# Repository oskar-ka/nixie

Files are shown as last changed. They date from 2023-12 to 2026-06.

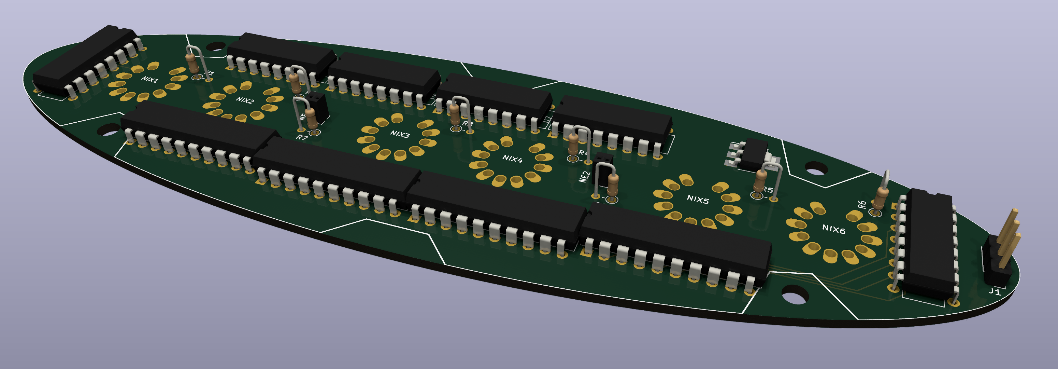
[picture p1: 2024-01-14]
pcb_v0/exports/renders/render.png

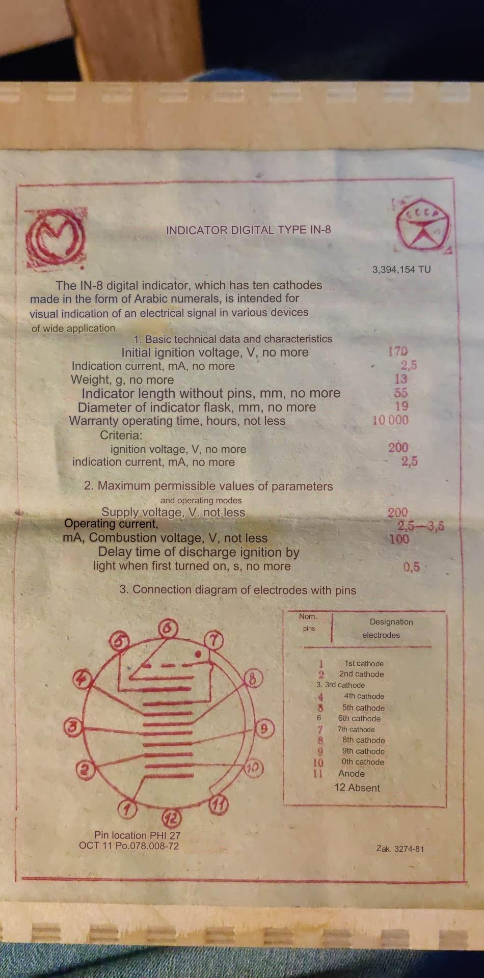
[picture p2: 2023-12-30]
datasheets/IN-8_datasheet_english.jpg

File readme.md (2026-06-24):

# Features
- 6x IN-8
- 2/4x NE-2
- GPS disciplined, temperature compensated crystal oscillator
- Lysnetspænding i EU kan lovligt variere mellem 207Vac til 253Vac, som giver halveret DC på 146-182Vdc
- Automatisk lysstyrkedæmpning
- Temperaturføler
- Komponenter skal virke ved 85C (varm dag &leq;40C+4W*10K/W=80C)

# Strømforsyning
Nixie uret skal bruge to spændinger for at fungere: 5Vdc til microcontroller og logiske kredse, samt 180Vdc til at trække nixierørene. Hvert rør kan tåle op til 3.5mA, så med 6 rør skal strømforsyningen levere 21mA + lidt til de 4 små nixie prikker, så i alt maks. 30mA v. 180Vdc. Det er nok ikke nødvendigt med PFC ved 30mA, men det kunne måske være sjovt at lave hvis der er plads til det. Evt. kan strøforsyningen blive lavet på et separat print, som kan placeres under nixie-printet, så burde der være masser af plads. Skal den kunne skifte mellem 230Vac og 120Vac, og skal den gøre det automatisk?

### Specifikationer
- Fra IN-8 datablad:
    - Ignition voltage: &leq; 170V
    - Indication current: &leq; 2.5mA
    - Turn-off voltage: ??
- NE-2 lampe:
    - &lt;1mA
- 180Vdc, 20mA
- Current limiting, [foldback](https://www.eeeguide.com/foldback-current-limiting-circuit/)

### Der findes mange forskellige måder at opnå disse to spændinger:
- 12/24Vdc indgang &rarr; DC-DC til 5V + boost converter til 180Vdc
    - [Recom R12-150B](https://www.tme.eu/dk/en/details/r12-150b/dc-dc-converters/recom/)
- 230Vac indgang &rarr; diodebro som giver 325Vdc, med den rigtige modstand før 
nixierørene kan denne spænding bruges direkte; 5V AC-DC
    - Rimelig ueffektivt og ikke så sejt, men meget nemt
    - Nixiestrøm afhængig af netspænding
- 230Vac &rarr; styret thyristorbro som giver 180Vdc direkte; 5V AC-DC
    - Thyristorbroer er som regel store, ved ikke om man kan få en i DIP
- 230Vac &rarr; styret MOSFET ensretter som giver 180Vdc direkte; 5V AC-DC
    - Mere effektiv end thyristorbro
    - Skal bruge to MOSFETS hver vej for at kunne blokere = 8 MOSFETS
    - Kan evt. også laves som halvbølgeensretter, da den ikke skal levere ret meget strøm
- ~~230Vac &rarr; halveringstransformer 230V&rarr;115Vac &rarr; ensretter (styret/ikke styret); & 5V AC-DC~~
    - ~~Ret nemt, få komponenter, ret effektivt, galvanisk adskillelse~~
    - ~~Giver 160Vdc v. 230Vac, hvilket er fint, men hvis nettet går ned til 207Vdc så har vi kun 146Vdc hvilket ikke helt er nok~~
- 230Vac &rarr; 2/3-transformer = 195/217/239Vdc (min, nom, max)
    - enten direkte til nixierør, kunne sikkert fungere
        - Her vil varmetab være i modstande og måske IC, bedre at have det centreret i en NPN med varmeplade
    - eller transistor med varmetab
        - skal smide mellem 15-59V
        - ved 20mA &rarr; 0.3W-1.2W
        - TO-92: [PHE13003A](https://mou.sr/43Gdbwc) 60K/W, nogle af dem måske op til 2W??
        - TO-252 [MJD340](https://mou.sr/4o38ar5): 8.3K/W op til 15W
        - TO-220 [BUL741](https://mou.sr/3Q8gnh7): 2K/W op til 60W
        - TO-3 [MJ15024](https://mou.sr/4uGqn01): 0.7K/W op til 250W
    - eller buck-converter?
- 230Vac &rarr; reguleret flyback converter med 2 udgange!!
    - Ret sej løsning, galvanisk adskillelse, høj virkningsgrad, ikke nemt.
    - 

Skal power supply være på et separat print?

### Varmeplader
- Fischer Eletronik SK 13
    - 17 K/W
    - Lille U-formet, mindste heatsink som kan bruges
    - Højde: 13mm
- Mindste PCB mount
    - [link](https://www.digikey.com/en/products/detail/boyd-laconia-llc/581002B02500G/1216391)
    - 17.4 K/W
    - Højde: 25.4mm
- Fischer Elektronik SK 64
    - 2.7 K/W
    - Fås i [sort](https://www.digikey.com/en/products/detail/fischer-elektronik/SK-64-37-5-SA-1-x-M3-TO-220/25827581) eller [natural](https://www.digikey.com/en/products/detail/fischer-elektronik/SK-64-37-5-ME-1-x-M3-TO-220/25828864)
    - Højde: 25mm
- [SK 65](https://fischerelektronik.de/web_fischer/en/heatsinks/A01/Standard%20extruded%20heatsinks/$catalogue/fischerData/PR/SK65_/search.xhtml) Til SOT-32 transistor, lidt lavere end SK 64
- [U-formet](https://fischerelektronik.de/web_fischer/en/heatsinks/A07/U-Extruded%20heatsinks/$catalogue/fischerData/PR/ICK35_SA_/search.xhtml), lidt større end den jeg har, 15K/W
- ~~[SK 36](https://fischerelektronik.de/web_fischer/en/heatsinks/A01/Standard%20extruded%20heatsinks/$catalogue/fischerData/PR/SK36_/search.xhtml) Sej en til TO-3~~
- [SK 31](https://fischerelektronik.de/web_fischer/en/heatsinks/A01/Standard%20extruded%20heatsinks/$catalogue/fischerData/PR/SK31_/search.xhtml) Til TO-3, kun 12mm høj
- [SK 145](https://www.fischerelektronik.de/web_fischer/en_GB/heatsinks/A01/Standard%20extruded%20heatsinks/$catalogue/fischerData/PR/SK145_/search.xhtml)
- SK 59
- SK 09
- Adam tech
    - HSK-53-01 Højde: 18.5mm
    - HSK-55-01 Højde: 18.5mm
- [680-5A](https://mou.sr/4eQcQgR)
    - 12.7mm højde
    - 46x46mm footprint

### Komponenter
- AC Sikring + sikringsholder
    - 100mA glassikring?
- Transformer:
    - [Hammond 229A230](https://www.digikey.com/en/products/detail/hammond-manufacturing/229A230/454947) Unhoused
        - Height: 21.6mm
    - [Bel Signal IF-6-230](https://mou.sr/49APmcG) Red housing
        - Height: 22.6mm
    - [Bel Signal 230-25-LPI](https://mou.sr/4x3g8o8) Black housing
        - Height: 22.7mm
    - [Bel Signal LP-230-25](https://mou.sr/4uTkMDK) Unhoused
        - Height: 21.6mm
- 5V supply:
    - [Mean Well IRM-01-5](https://mou.sr/4u9H5E1)
    - [PBO-3E/F](https://www.belfuse.com/products/power-supplies/ac-dc-converters)
    - [PSK-5E](https://www.belfuse.com/products/power-supplies/ac-dc-converters/psk-5e-series)
    - [TRACO Power TMPS 05-105](https://mou.sr/49ALLeS) 1x1"
    - [Mornsun LS05-23B05DR3](https://www.mornsun-power.com/html/pdf/LS05-23B05DR3.html) Very small
- Ensretter IC
    - sdf

# Timekeeping
Forskellige niveauer af præcision: MCUens interne RC oscillator, normal kvartskrystal, temperaturkonpenseret krystaloscillator (TCXO), ovnkontrolleret krystaloscillator (OCXO). Desuden kan en oscillator *disciplineres* mht. et præcist eksternt signal, f.eks. GPS for en stor forbedring i stabilitet.

Stratum 3??

- OCXO
    - [CTS 139VGEVS10M000](https://mou.sr/4afKvxZ)
    - Bruger en lille "ovn" til at opvarme krystallen og holde dens temperatur stabil
- TCXO
    - Typisk tilgændelige i 280ppb, hvilket er super
    - De har god temperaturstabilitet, men ikke nødvedigvis god *aging*
    - MEMS vs quartz. MEMS har bedre aging, bedre temperaturforudsigelighed, bedre dynamisk stabilitet (når temp. ændrer sig), lavere fejlrater. De er dog dyrere, har mere fasestøj, og bruger mere strøm.
    - [SiTime MEMS](https://www.sitime.com/products/ultrastable-mhz-super-tcxos/super-tcxos/sit5356)

Vi vil gerne under 1s afvigelse over et år uden GPS, dette 

# Udførsel, lagkagekasse
Bruger den første kasse der blev bygget, den laserskårede. 
6 IN-8 rør, 2 NE-2 lamper. Ingen optokoblere. 
Forsynet med 170V reguleret direkte fra ensrettet mains, derudover lille indpakket 5V AC-DC forsyning. 
Forsyning på separat print, som hænger under styreprint med 20mm standoffs, og bruger disse til forbindelse.
Ensretter, CRC filter, TO-3 transistor, (en cap mere?)
Strømindgang via IEC C7 stik uden ground, intet at bruge det til.

# Komponenter, generel
- Lamper
    - 6x IN-8
    - 2/4x NE-2
- Forsyningsprint
    - Sikring
        - 100mA
    - Transformer
    - Ensretter
    - Lyt
    - Zenerdiode(r)
        - hvis 180V så 5W
    - Effekttransistor
    - OCP transistor
    - Modstande
    - AC-DC forsyning
- Styreprint
    - ATtiny2313 x1
    - Shift register x4
    - Quad optokobler f.eks. LTV-845M x4
    - SN74141 x4
    - MPSA42 NPN transistor
    - 6x Anodemodstande til nixierør 1/2W
    - 2x Anodemodstande til NE2 lamper 1/4W

# Enclosure
### Varmeafgivelse
- Original laserskåret lagkagekasse
    - Test 1: P=4W, UT=22C, IT=67C &rarr; +45C v. 4W = 11.25 K/W
    - Test 2: P=3W, UT=22C, IT=58C &rarr; +36C v. 3W = 12    K/W
    - Test 3: P=2W, UT=22C, IT=49C &rarr; +26C v. 2W = 13.5  K/W
    - Test 4: P=1W, UT=22C, IT=38C &rarr; +16C v. 1W = 16    K/W
    
SMD keramiske kondensatorer 2.2uF 450V [her](https://mou.sr/4eBqHqi)

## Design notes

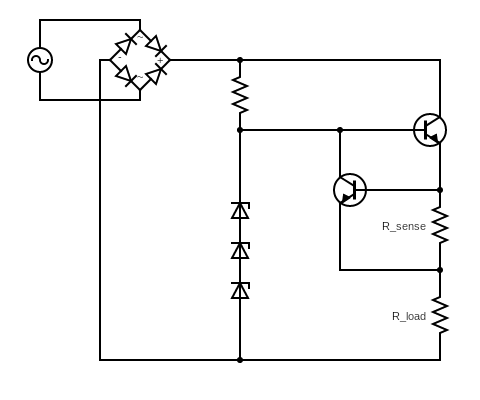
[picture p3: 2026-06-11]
HV_regulator_I_limit.png

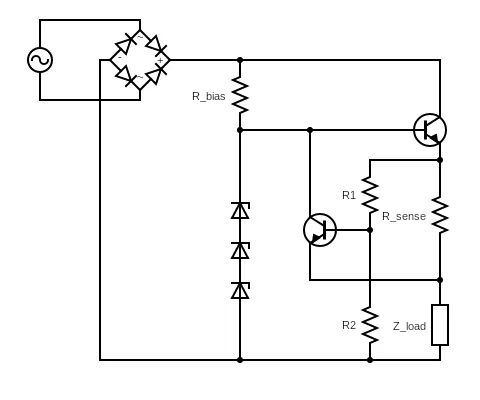
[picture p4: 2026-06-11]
HV_regulator_foldback.png

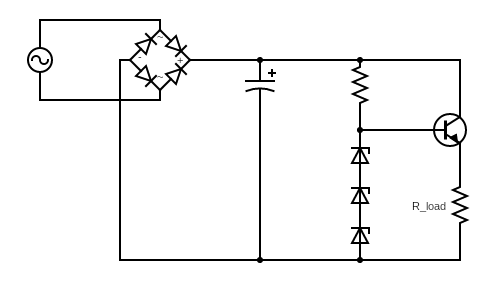
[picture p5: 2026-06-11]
HV_regulator.png

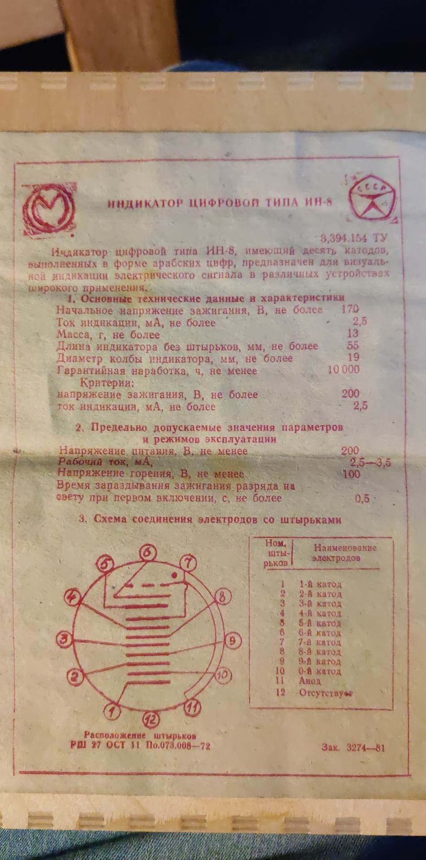
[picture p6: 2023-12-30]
datasheets/318470724_1155964738362694_6747269933038089957_n.jpg

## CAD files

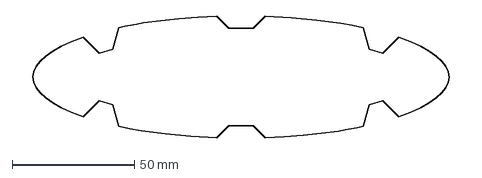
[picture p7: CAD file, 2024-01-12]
pcb_v0/pcb_component_clearance.dxf
183.7 x 49.7 mm

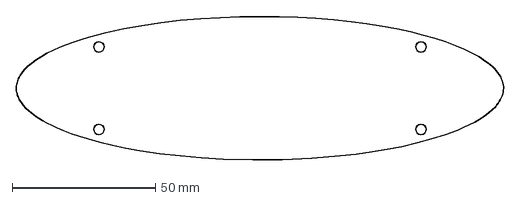
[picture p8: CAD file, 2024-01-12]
pcb_v0/pcb_edge_cuts.dxf
170.0 x 50.5 mm

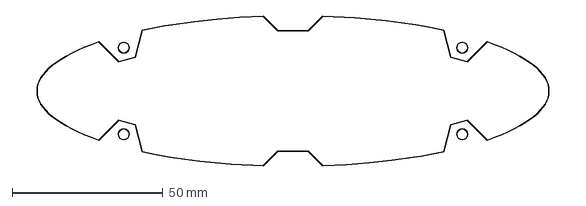
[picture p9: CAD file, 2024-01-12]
pcb_v0/nixie_clock_ellipseshape_with_mounting.dxf
183.7 x 49.7 mm

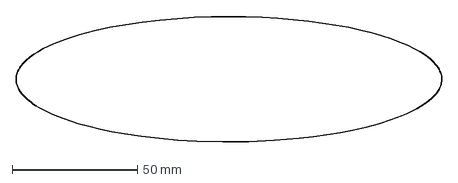
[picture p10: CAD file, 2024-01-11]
pcb_v0/nixie_clock_ellipseshape.dxf
170.0 x 50.5 mm

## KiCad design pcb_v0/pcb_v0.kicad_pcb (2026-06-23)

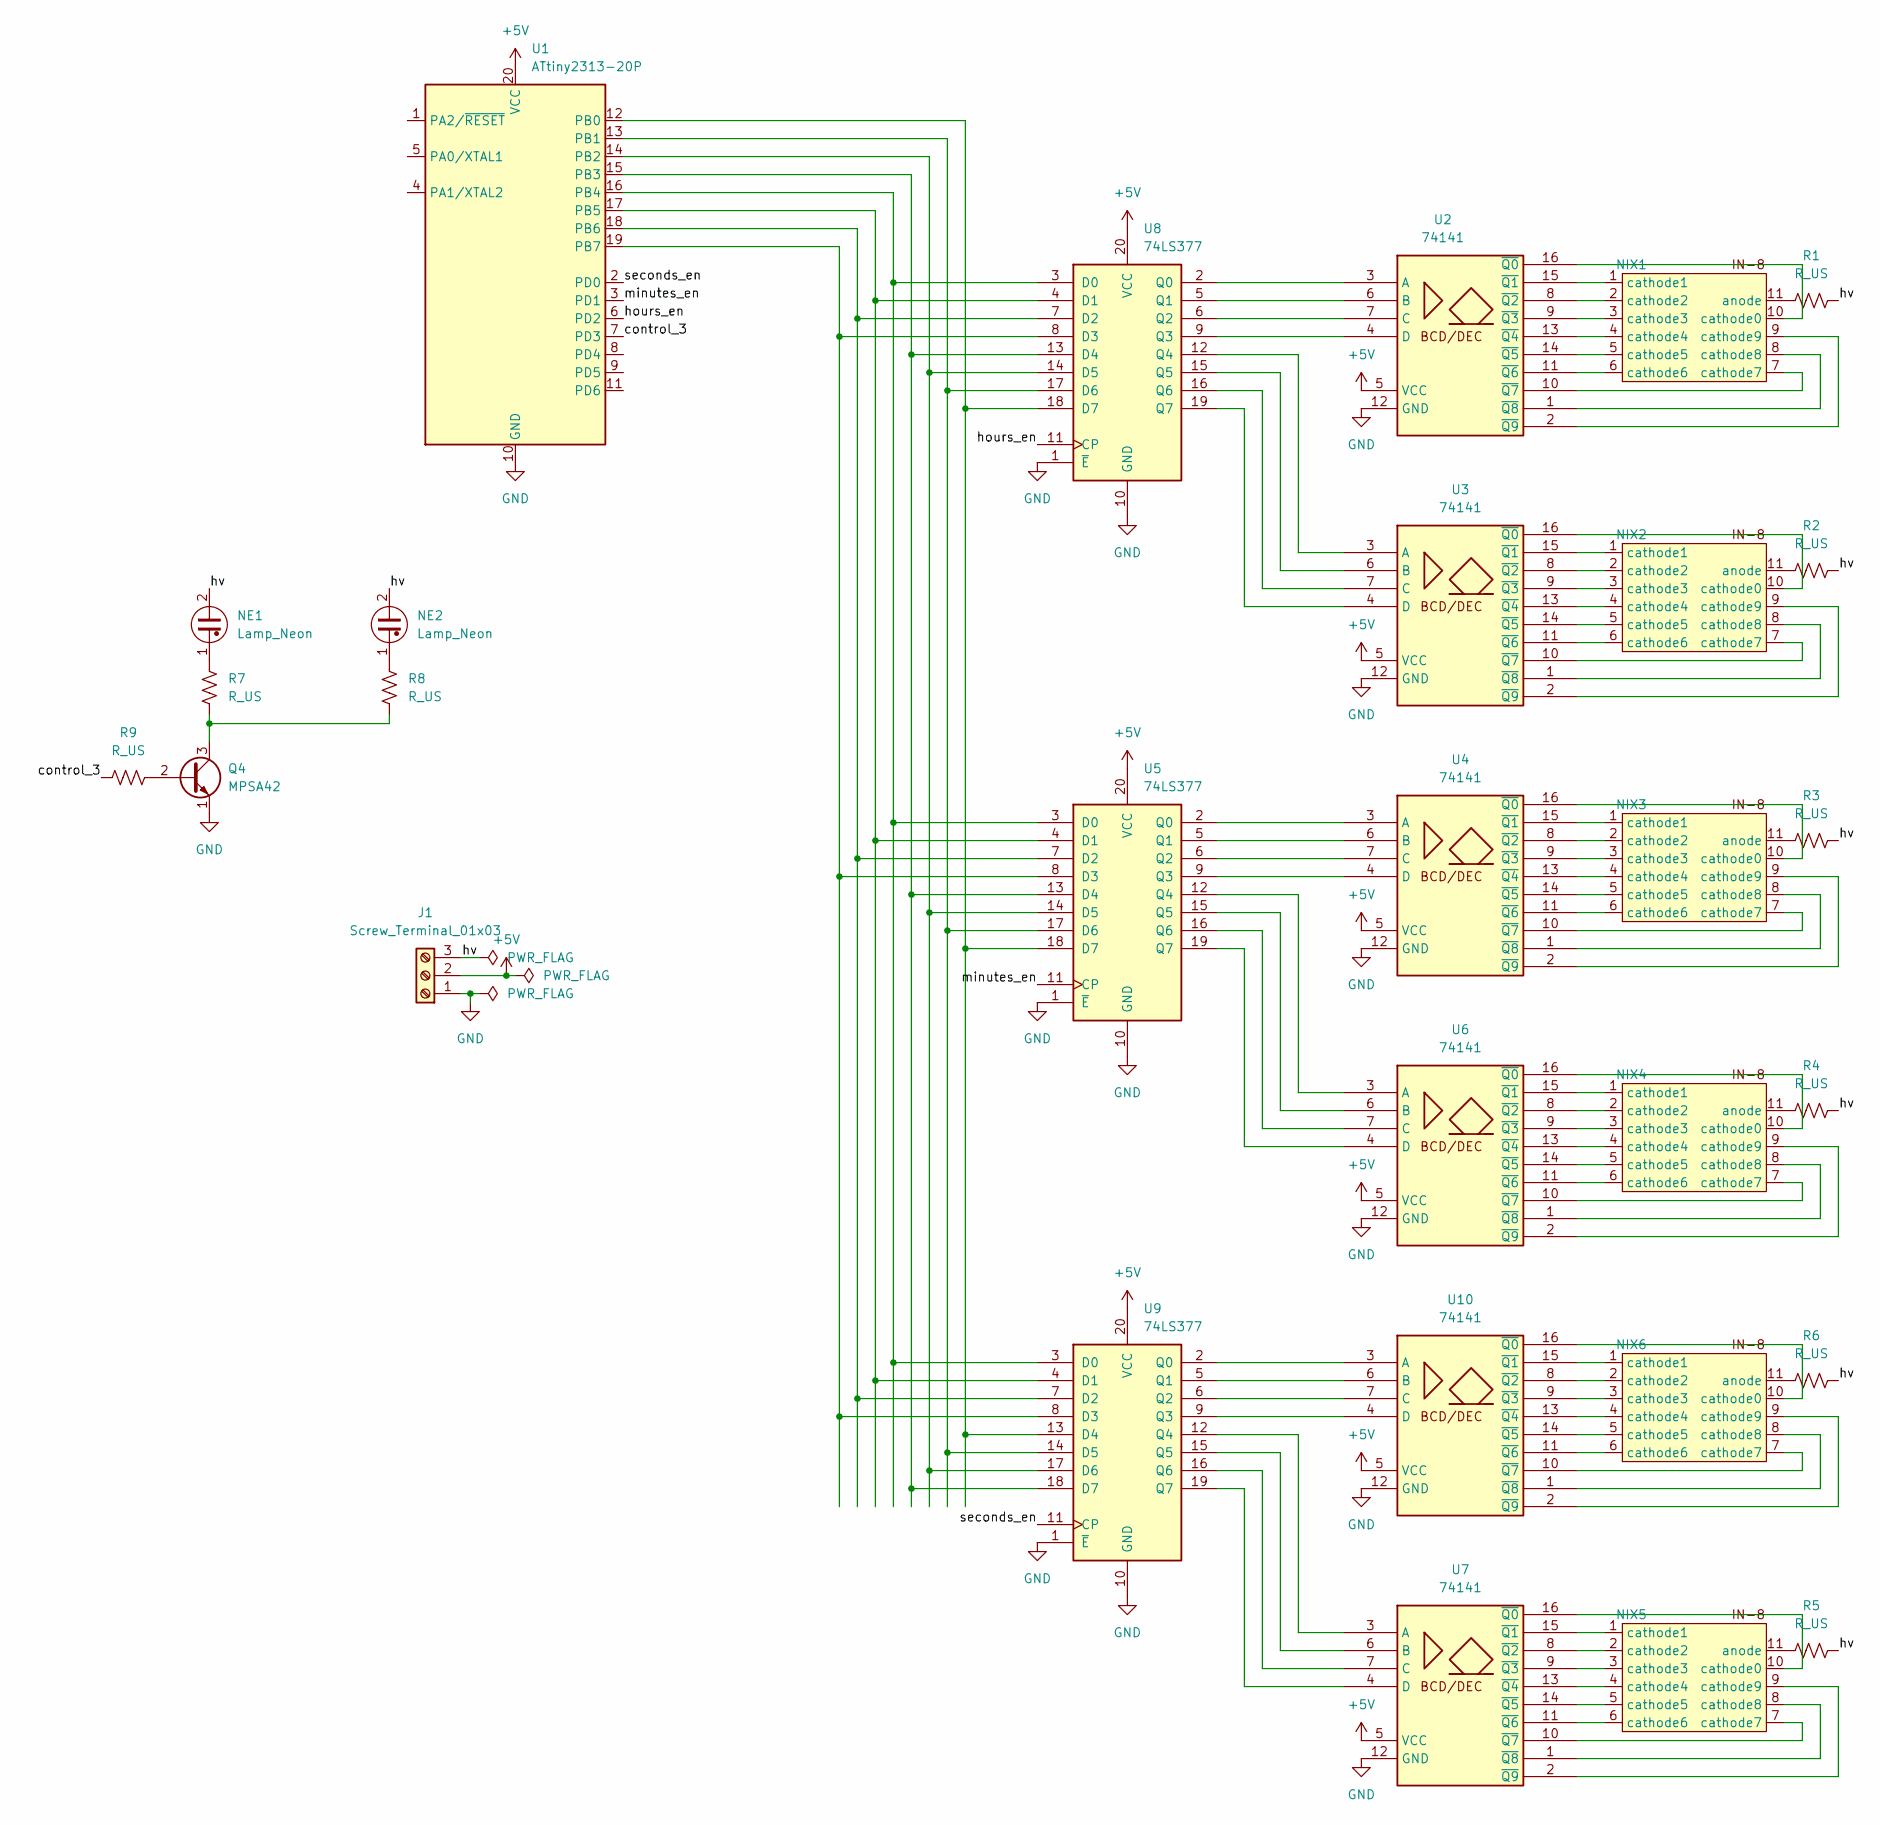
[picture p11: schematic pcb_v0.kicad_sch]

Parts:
J1: Screw_Terminal_01x03; PinHeader_1x03_P2.54mm_Vertical
NE1, NE2: Lamp_Neon; PinSocket_1x02_P1.27mm_Vertical
NIX1, NIX2, NIX3, NIX4, NIX5, NIX6: in-8
Q4: MPSA42; TO-92_Inline
R1, R2, R3, R4, R5, R6: R_US; R_Axial_DIN0309_L9.0mm_D3.2mm_P12.70mm_Horizontal
R7, R8, R9: R_US; R_Axial_DIN0207_L6.3mm_D2.5mm_P7.62mm_Horizontal
U1: ATtiny2313-20P; DIP-20_W7.62mm
U2, U3, U4, U6, U7, U10: 74141; DIP-16_W7.62mm
U5, U8, U9: 74LS377; DIP-20_W7.62mm

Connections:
+5V: J1.2, U1.20 (VCC), U2.5 (VCC), U3.5 (VCC), U4.5 (VCC), U5.20 (VCC), U6.5 (VCC), U7.5 (VCC), U8.20 (VCC), U9.20 (VCC), U10.5 (VCC)
/control_3: R9.2, U1.7 (PD3)
/hours_en: U1.6 (PD2), U8.11 (CP)
/hv: J1.3, NE1.2, NE2.2, R1.2, R2.2, R3.2, R4.2, R5.2, R6.2
/minutes_en: U1.3 (PD1), U5.11 (CP)
/seconds_en: U1.2 (PD0), U9.11 (CP)
GND: J1.1, Q4.1 (E), U1.10 (GND), U2.12 (GND), U3.12 (GND), U4.12 (GND), U5.1 (~E), U5.10 (GND), U6.12 (GND), U7.12 (GND), U8.1 (~E), U8.10 (GND), U9.1 (~E), U9.10 (GND), U10.12 (GND)
unnamed: NE1.1, R7.2
unnamed: NE2.1, R8.2
unnamed: NIX1.11 (anode), R1.1
unnamed: NIX1.10 (cathode0), U2.16 (~Q0)
unnamed: NIX1.1 (cathode1), U2.15 (~Q1)
unnamed: NIX1.2 (cathode2), U2.8 (~Q2)
unnamed: NIX1.3 (cathode3), U2.9 (~Q3)
unnamed: NIX1.4 (cathode4), U2.13 (~Q4)
unnamed: NIX1.5 (cathode5), U2.14 (~Q5)
unnamed: NIX1.6 (cathode6), U2.11 (~Q6)
unnamed: NIX1.7 (cathode7), U2.10 (~Q7)
unnamed: NIX1.8 (cathode8), U2.1 (~Q8)
unnamed: NIX1.9 (cathode9), U2.2 (~Q9)
unnamed: NIX2.11 (anode), R2.1
unnamed: NIX2.10 (cathode0), U3.16 (~Q0)
unnamed: NIX2.1 (cathode1), U3.15 (~Q1)
unnamed: NIX2.2 (cathode2), U3.8 (~Q2)
unnamed: NIX2.3 (cathode3), U3.9 (~Q3)
unnamed: NIX2.4 (cathode4), U3.13 (~Q4)
unnamed: NIX2.5 (cathode5), U3.14 (~Q5)
unnamed: NIX2.6 (cathode6), U3.11 (~Q6)
unnamed: NIX2.7 (cathode7), U3.10 (~Q7)
unnamed: NIX2.8 (cathode8), U3.1 (~Q8)
unnamed: NIX2.9 (cathode9), U3.2 (~Q9)
unnamed: NIX3.11 (anode), R3.1
unnamed: NIX3.10 (cathode0), U4.16 (~Q0)
unnamed: NIX3.1 (cathode1), U4.15 (~Q1)
unnamed: NIX3.2 (cathode2), U4.8 (~Q2)
unnamed: NIX3.3 (cathode3), U4.9 (~Q3)
unnamed: NIX3.4 (cathode4), U4.13 (~Q4)
unnamed: NIX3.5 (cathode5), U4.14 (~Q5)
unnamed: NIX3.6 (cathode6), U4.11 (~Q6)
unnamed: NIX3.7 (cathode7), U4.10 (~Q7)
unnamed: NIX3.8 (cathode8), U4.1 (~Q8)
unnamed: NIX3.9 (cathode9), U4.2 (~Q9)
unnamed: NIX4.11 (anode), R4.1
unnamed: NIX4.10 (cathode0), U6.16 (~Q0)
unnamed: NIX4.1 (cathode1), U6.15 (~Q1)
unnamed: NIX4.2 (cathode2), U6.8 (~Q2)
unnamed: NIX4.3 (cathode3), U6.9 (~Q3)
unnamed: NIX4.4 (cathode4), U6.13 (~Q4)
unnamed: NIX4.5 (cathode5), U6.14 (~Q5)
unnamed: NIX4.6 (cathode6), U6.11 (~Q6)
unnamed: NIX4.7 (cathode7), U6.10 (~Q7)
unnamed: NIX4.8 (cathode8), U6.1 (~Q8)
unnamed: NIX4.9 (cathode9), U6.2 (~Q9)
unnamed: NIX5.11 (anode), R5.1
unnamed: NIX5.10 (cathode0), U7.16 (~Q0)
unnamed: NIX5.1 (cathode1), U7.15 (~Q1)
unnamed: NIX5.2 (cathode2), U7.8 (~Q2)
unnamed: NIX5.3 (cathode3), U7.9 (~Q3)
unnamed: NIX5.4 (cathode4), U7.13 (~Q4)
unnamed: NIX5.5 (cathode5), U7.14 (~Q5)
unnamed: NIX5.6 (cathode6), U7.11 (~Q6)
unnamed: NIX5.7 (cathode7), U7.10 (~Q7)
unnamed: NIX5.8 (cathode8), U7.1 (~Q8)
unnamed: NIX5.9 (cathode9), U7.2 (~Q9)
unnamed: NIX6.11 (anode), R6.1
unnamed: NIX6.10 (cathode0), U10.16 (~Q0)
unnamed: NIX6.1 (cathode1), U10.15 (~Q1)
unnamed: NIX6.2 (cathode2), U10.8 (~Q2)
unnamed: NIX6.3 (cathode3), U10.9 (~Q3)
unnamed: NIX6.4 (cathode4), U10.13 (~Q4)
unnamed: NIX6.5 (cathode5), U10.14 (~Q5)
unnamed: NIX6.6 (cathode6), U10.11 (~Q6)
unnamed: NIX6.7 (cathode7), U10.10 (~Q7)
unnamed: NIX6.8 (cathode8), U10.1 (~Q8)
unnamed: NIX6.9 (cathode9), U10.2 (~Q9)
unnamed: Q4.2 (B), R9.1
unnamed: Q4.3 (C), R7.1, R8.1
unnamed: U1.12 (PB0), U5.18 (D7), U8.18 (D7), U9.13 (D4)
unnamed: U1.13 (PB1), U5.17 (D6), U8.17 (D6), U9.14 (D5)
unnamed: U1.14 (PB2), U5.14 (D5), U8.14 (D5), U9.17 (D6)
unnamed: U1.15 (PB3), U5.13 (D4), U8.13 (D4), U9.18 (D7)
unnamed: U1.16 (PB4), U5.3 (D0), U8.3 (D0), U9.3 (D0)
unnamed: U1.17 (PB5), U5.4 (D1), U8.4 (D1), U9.4 (D1)
unnamed: U1.18 (PB6), U5.7 (D2), U8.7 (D2), U9.7 (D2)
unnamed: U1.19 (PB7), U5.8 (D3), U8.8 (D3), U9.8 (D3)
unnamed: U2.3 (A), U8.2 (Q0)
unnamed: U2.6 (B), U8.5 (Q1)
unnamed: U2.7 (C), U8.6 (Q2)
unnamed: U2.4 (D), U8.9 (Q3)
unnamed: U3.3 (A), U8.12 (Q4)
unnamed: U3.6 (B), U8.15 (Q5)
unnamed: U3.7 (C), U8.16 (Q6)
unnamed: U3.4 (D), U8.19 (Q7)
unnamed: U4.3 (A), U5.2 (Q0)
unnamed: U4.6 (B), U5.5 (Q1)
unnamed: U4.7 (C), U5.6 (Q2)
unnamed: U4.4 (D), U5.9 (Q3)
unnamed: U5.12 (Q4), U6.3 (A)
unnamed: U5.15 (Q5), U6.6 (B)
unnamed: U5.16 (Q6), U6.7 (C)
unnamed: U5.19 (Q7), U6.4 (D)
unnamed: U7.3 (A), U9.12 (Q4)
unnamed: U7.6 (B), U9.15 (Q5)
unnamed: U7.7 (C), U9.16 (Q6)
unnamed: U7.4 (D), U9.19 (Q7)
unnamed: U9.2 (Q0), U10.3 (A)
unnamed: U9.5 (Q1), U10.6 (B)
unnamed: U9.6 (Q2), U10.7 (C)
unnamed: U9.9 (Q3), U10.4 (D)

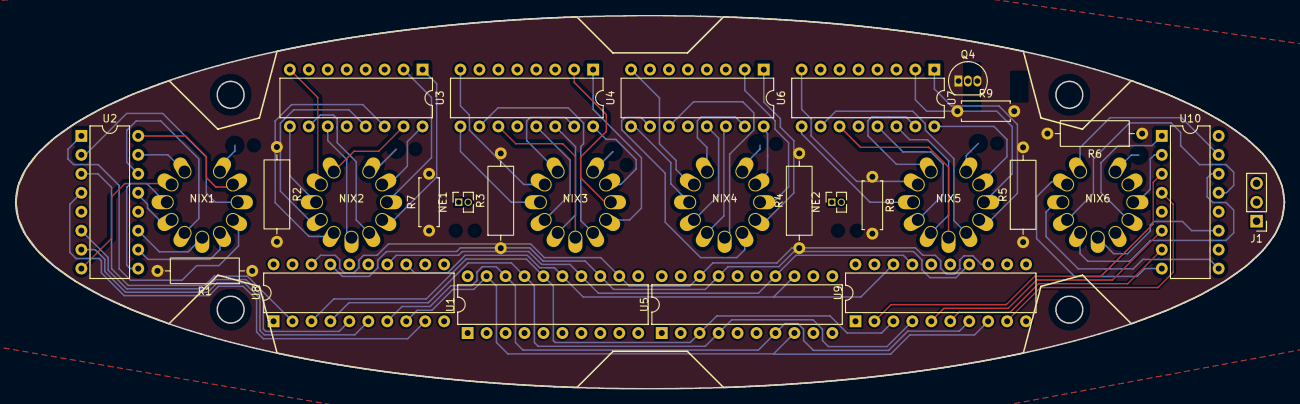
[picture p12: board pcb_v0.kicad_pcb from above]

Board: 2 copper layers, 170.0 x 50.0 mm, 29 parts (0 on the bottom side), 109 nets.

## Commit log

2022-12-29 Update voltage_mult - Copy.asc
2023-01-28 Created kiCAD project
    [nixie_pcb.kicad_pcb, nixie_pcb.kicad_sch]
2023-01-30 Schem from ltspice to kicad
    [nixie_pcb.kicad_sch]
2023-12-22 added files for new circuit
2023-12-30 created new kicad project
    [nixie_pcb.kicad_pcb, nixie_pcb.kicad_sch, pcb_v0.kicad_pcb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]
2024-01-07 Added symbols for 74141 and in-8
    [pcb_v0.kicad_sch]
2024-01-12 ATtiny and flip flops routed
    [pcb_v0.kicad_pcb, pcb_v0.kicad_sch]
2024-01-12 new outline, now nothing fits
    [nixie_clock_ellipseshape_with_mounting.dxf, pcb_v0.kicad_pcb]
2024-01-12 registers wired correctly this time
    [pcb_v0.kicad_pcb, pcb_v0.kicad_sch]
2026-05-13 PSU discussion
    [nixie_clock_ellipseshape.dxf, nixie_clock_ellipseshape_with_mounting.dxf, pcb_component_clearance.dxf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]
